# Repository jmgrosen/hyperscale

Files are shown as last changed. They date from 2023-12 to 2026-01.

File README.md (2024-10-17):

# Hyperscale

A kitchen scale that helps you follow a recipe.

## Building

Export Gerbers from KiCAD for the PCB. Build STLs from OpenSCAD for the case.

An actual assembly guide is TODO!

For the firmware, install [the Xtensa rustc target](https://docs.esp-rs.org/book/installation/riscv-and-xtensa.html) and [espflash](https://docs.esp-rs.org/book/tooling/espflash.html) as described in the Rust on ESP Book. Then `cargo espflash flash`.

## Licensing

The physical design files are licensed under the CERN Open Hardware Licence Version 2 - Permissive.

The firmware code is licensed under MIT. However, due to its use of Slint, the resulting firmware as a whole is licensed under GPLv3.

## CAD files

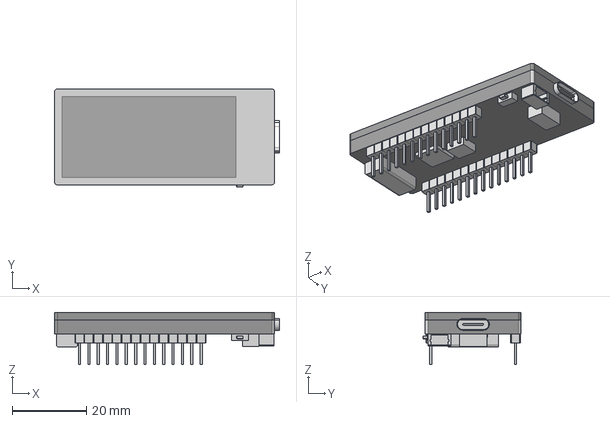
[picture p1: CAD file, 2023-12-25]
pcb/LILYGO T-Display-S3-AMOLED-Model.step
60.8 x 26.5 x 14.2 mm

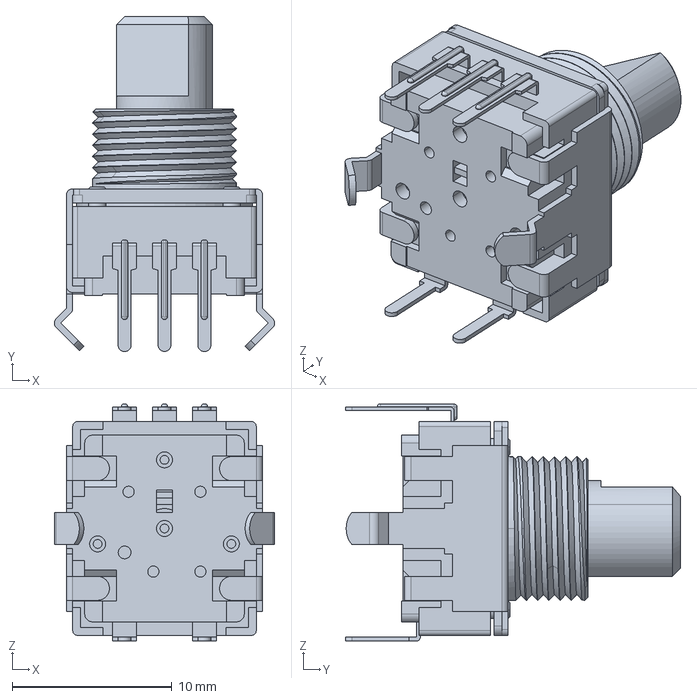
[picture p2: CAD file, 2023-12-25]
pcb/pec12r-3x17f-sxxxx.stp
13.8 x 21.0 x 14.8 mm

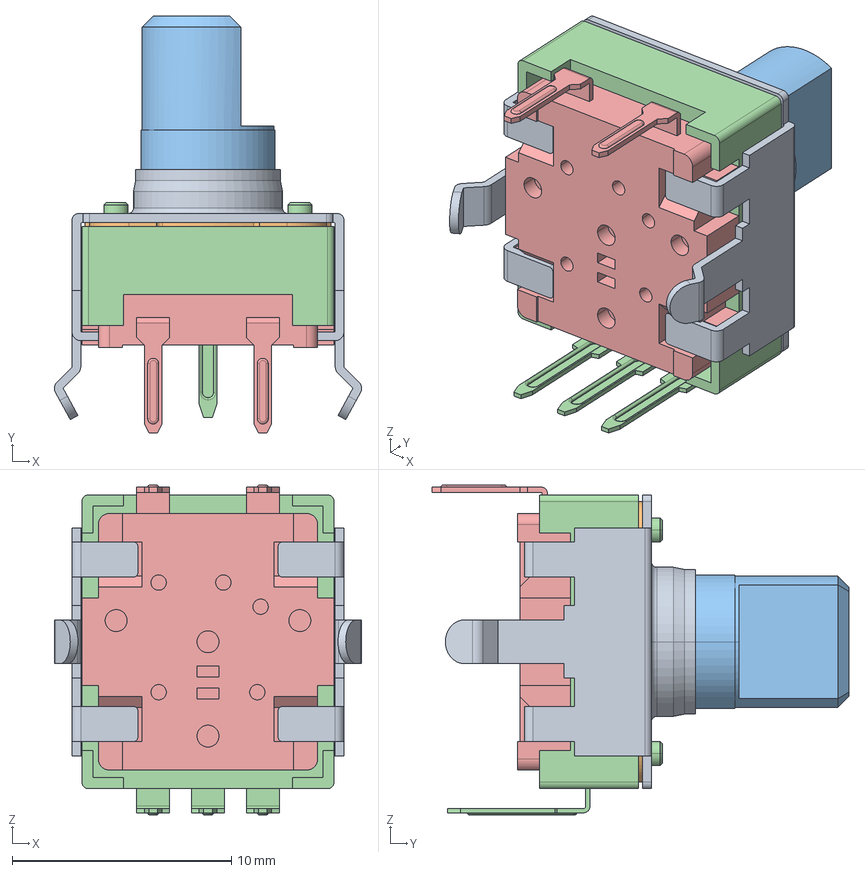
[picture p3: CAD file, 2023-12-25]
pcb/pec12r-4215f-s0024.stp
14.0 x 19.0 x 15.1 mm
12-24-B
12-32-Y
12-14-C

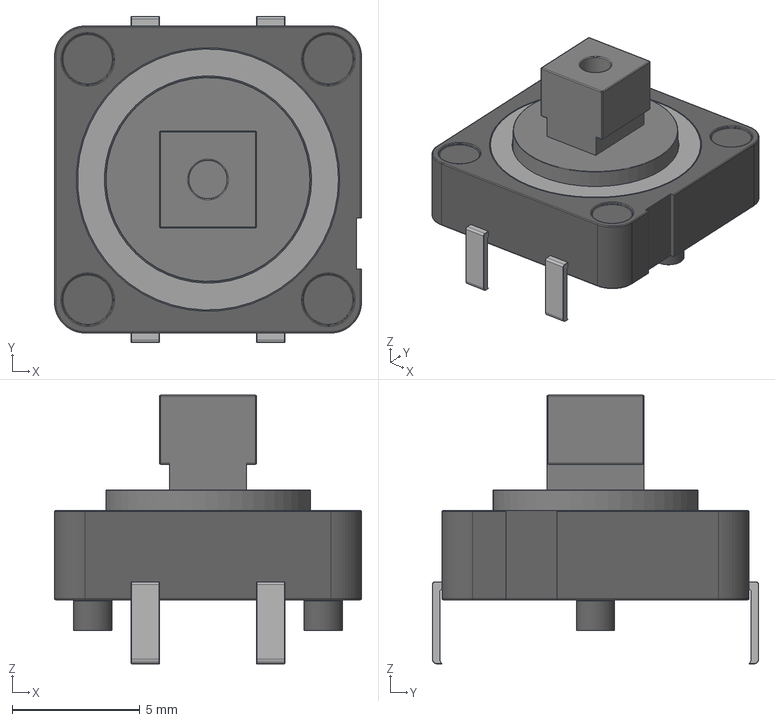
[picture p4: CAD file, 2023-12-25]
pcb/button round 12mm.step
12.0 x 12.8 x 10.5 mm

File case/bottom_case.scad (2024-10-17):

// Copyright (C) Jessie Grosen 2024
// SPDX-License-Identifier: CERN-OHL-P-2.0

include <BOSL2/std.scad>
include <BOSL2/rounding.scad>

include <common.scad>

/*
  ALL MEASUREMENTS IN MM
 */

/*
  TODO:
 */

PREVIEW = false;
PROTOTYPING = true;


strain_relief_maze = union([
  translate([0, 0], p=rect([STRAIN_RELIEF_WIDTH, BEND_RADIUS+2*STRAIN_RELIEF_WIDTH], anchor=TOP+LEFT)),
  translate([0, -BEND_RADIUS-STRAIN_RELIEF_WIDTH], p=rect([BEND_RADIUS+2*STRAIN_RELIEF_WIDTH, STRAIN_RELIEF_WIDTH], anchor=TOP+LEFT)),
  translate([BEND_RADIUS+STRAIN_RELIEF_WIDTH, 0], p=rect([BEND_RADIUS+2*STRAIN_RELIEF_WIDTH, STRAIN_RELIEF_WIDTH], anchor=TOP+LEFT)),
  translate([2*BEND_RADIUS+2*STRAIN_RELIEF_WIDTH, 0], p=rect([STRAIN_RELIEF_WIDTH, BEND_RADIUS*2+3*STRAIN_RELIEF_WIDTH], anchor=TOP+LEFT)),
  translate([BEND_RADIUS+STRAIN_RELIEF_WIDTH, -2*BEND_RADIUS-2*STRAIN_RELIEF_WIDTH], p=rect([BEND_RADIUS+2*STRAIN_RELIEF_WIDTH, STRAIN_RELIEF_WIDTH], anchor=TOP+LEFT)),
]);

rounding_start_depth = TOTAL_DEPTH - BACK_ROUNDING_RADIUS;
back_bottom_width = ROUNDING_START_WIDTH - 2*BACK_ROUNDING_RADIUS;
diagonal_width = (FRONT_BOTTOM_WIDTH - ROUNDING_START_WIDTH) / 2;
magnet_wall_offset = WIRE_TO_MAGNET_DIST + MAGNET_DIAMETER/2 + WALL_WIDTH;
base = move([-FRONT_BOTTOM_WIDTH/2, -TOTAL_DEPTH/2, 0], turtle([
  "turn", 90,
  "xymove", [diagonal_width, rounding_start_depth],
  "arcright", BACK_ROUNDING_RADIUS, 90,
  "move", back_bottom_width/2 - magnet_wall_offset,
  "turn", -90,
  "move", MAGNET_WALL_DEPTH_OFFSET,
  "turn", 90,
  "move", magnet_wall_offset * 2,
  "turn", 90,
  "move", MAGNET_WALL_DEPTH_OFFSET,
  "turn", -90,
  "move", back_bottom_width/2 - magnet_wall_offset,
  "arcright", BACK_ROUNDING_RADIUS, 90,
  "xymove", [diagonal_width, -rounding_start_depth],
]));

module below_pcb() {
  half_of(xrot(TILT_ANGLE, p=DOWN), cp=[0, 0, PCB_CENTER_HEIGHT], s=FRONT_BOTTOM_WIDTH*3)
    linear_extrude(height=TOP_CENTER_HEIGHT*2)
      polygon(base);
}

linear_extrude(height=BOTTOM_HEIGHT) polygon(base);

tilt_height = (TOTAL_DEPTH / 2) * tan(TILT_ANGLE);
total_height = TOP_CENTER_HEIGHT + tilt_height;

// perimeter wall
difference() {
  half_of(xrot(TILT_ANGLE, p=DOWN), cp=[0, 0, TOP_CENTER_HEIGHT], s=FRONT_BOTTOM_WIDTH*3)
    linear_extrude(height=TOP_CENTER_HEIGHT*2)
      offset_stroke(base, width=[0, -WALL_WIDTH], closed=true);
  translate([0, TOTAL_DEPTH / 2 - MAGNET_WALL_DEPTH_OFFSET, WIRE_HOLE_HEIGHT]) union() {
    teardrop(WALL_WIDTH*4, d=WIRE_HOLE_DIAMETER, $fn=20);
    if (PROTOTYPING) {
      cube([WIRE_HOLE_DIAMETER, WALL_WIDTH*4, TOP_CENTER_HEIGHT*2], anchor=BOTTOM);
    }
  }
  translate([0, 0, TOP_CENTER_HEIGHT-0.01]) xrot(TILT_ANGLE)
    translate(concat(PCB_OFFSET, [-BOTTOM_HEIGHT])) union() {
    for (cutout = FLANGE_CUTOUTS) {
      linear_extrude(height=BOTTOM_HEIGHT*3) polygon(cutout);
    }
  }
}

magnet_slot_rect = rect([MAGNET_DIAMETER, MAGNET_DEPTH]);

// magnet slots and strain relief
intersection() {
  below_pcb();
  union() {
    translate([0, TOTAL_DEPTH/2 - MAGNET_DEPTH/2 - MAGNET_WALL_DEPTH_OFFSET - WALL_WIDTH, 0]) xcopies(WIRE_TO_MAGNET_DIST * 2) {
      difference() {
        linear_extrude(height=MAGNET_HEIGHT) polygon(magnet_slot_rect);
        translate([0, -MAGNET_DEPTH/2 - 1, MAGNET_HEIGHT])
          #cylinder(h=MAGNET_DEPTH+2, d=MAGNET_DIAMETER, orient=BACK, $fn=40);
      }
      linear_extrude(height=MAGNET_HEIGHT + MAGNET_DIAMETER/2 + 1)
        offset_stroke(magnet_slot_rect, width=[0, WALL_WIDTH], closed=true);
    }
    color("blue") linear_extrude(total_height) translate([-BEND_RADIUS/2-STRAIN_RELIEF_WIDTH, 6, 0]) region(strain_relief_maze);
  }
}

intersection() {
  linear_extrude(height=total_height) polygon(base);
  // xrot(TILT_ANGLE) translate(concat(PCB_OFFSET, [PCB_CENTER_HEIGHT]))
  translate([0, 0, PCB_CENTER_HEIGHT])
    xrot(TILT_ANGLE)
      translate(PCB_OFFSET)
    color("red") union() {
    for (support = PCB_SUPPORTS) {
      zflip()
        linear_extrude(total_height)
          #region(support);
    }
    for (mount = MOUNT_POINTS) {
      translate(concat(mount, [0]))
        cylinder(MOUNT_POST_HEIGHT, r=MOUNT_POST_RADIUS, anchor=BOTTOM, $fn=20);
    }
  }
}

magnet_slot = translate([0, TOTAL_DEPTH/2], rect([magnet_wall_offset*2, MAGNET_WALL_DEPTH_OFFSET*4]));

translate([0, 0, TOP_CENTER_HEIGHT-0.01]) xrot(TILT_ANGLE)
// xrot(TILT_ANGLE) translate([0, 0, TOP_CENTER_HEIGHT-0.01])
union() {
  difference() {
    linear_extrude(height=BOTTOM_HEIGHT) union() {
      // offset_stroke(base, width=[0, -WALL_WIDTH]);
      region(difference(offset(top_flange, r=WALL_WIDTH, closed=true), base));
      offset_stroke(move([-FRONT_BOTTOM_WIDTH/2, -TOTAL_DEPTH/2, 0], turtle([
	"turn", 90,
	"xymove", [diagonal_width, rounding_start_depth],
	"arcright", BACK_ROUNDING_RADIUS, 90,
      ])), width=[0, -WALL_WIDTH], end="round");
      offset_stroke(move([FRONT_BOTTOM_WIDTH/2, -TOTAL_DEPTH/2, 0], turtle([
	"turn", 90,
	"xymove", [-diagonal_width, rounding_start_depth],
	"arcleft", BACK_ROUNDING_RADIUS, 90,
      ])), width=[0, WALL_WIDTH], end="round");
    }
    translate([0, 0, -1]) linear_extrude(height=FLANGE_HEIGHT+2) polygon(magnet_slot);
    translate(concat(PCB_OFFSET, [-BOTTOM_HEIGHT])) union() {
      for (cutout = FLANGE_CUTOUTS) {
	linear_extrude(height=BOTTOM_HEIGHT*3) polygon(cutout);
      }
    }
  }
  difference() {
    linear_extrude(height=FLANGE_HEIGHT) offset_stroke(top_flange, width=[0, -WALL_WIDTH], closed=true);
    translate([0, 0, -1]) linear_extrude(height=FLANGE_HEIGHT+2) polygon(magnet_slot);
  }
}


if (PREVIEW) {
  translate([0, 0, PCB_CENTER_HEIGHT])
  xrot(TILT_ANGLE)
    translate(PCB_OFFSET)
      import("../pcb/scale_pcb.stl");
}

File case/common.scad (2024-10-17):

// Copyright (C) Jessie Grosen 2024
// SPDX-License-Identifier: CERN-OHL-P-2.0

FRONT_BOTTOM_WIDTH = 117;
ROUNDING_START_WIDTH = 115;
BACK_ROUNDING_RADIUS = 15;
TOTAL_DEPTH=35.5;
BOTTOM_HEIGHT = 1.5;
WALL_WIDTH = 1;
TOP_CENTER_HEIGHT = 10;
PCB_CENTER_HEIGHT = 5;
TILT_ANGLE = 10;

PCB_OFFSET = [-144, 52.3];
MOUNT_POINTS = [
  [101.854, -45.974],
  // [145.796, -45.974],
  [145.796, -63.246],
  [184.324, -54.356],
];
MOUNT_POST_RADIUS = 1.4;
MOUNT_POST_HEIGHT = 3;

WIRE_HOLE_DIAMETER = 4;
WIRE_HOLE_HEIGHT = 5.5;
WIRE_TO_MAGNET_DIST = 11.25;
MAGNET_DEPTH = 3;
MAGNET_DIAMETER = 8;
MAGNET_HEIGHT = 5.75;
MAGNET_WALL_DEPTH_OFFSET = 2.5;

EXTRA_WIDTH_PER_SIDE = 9;
FLANGE_HEIGHT = 4;

// in PCB coordinates
FLANGE_CUTOUTS = [
  translate([209.42 - 9.5, -41.81 - 8.5], p=rect([6, 8.5], anchor=TOP+LEFT)), // battery connector: 5x8 at x=-9, y=-9
  translate([209.42 - 5.5, -41.81 - 17.8], p=rect([5.4, 7.3], anchor=TOP+LEFT)), // qwiic connector
  translate([209.42 - 12.5, -41.81 - 22.3], p=rect([6, 4], anchor=TOP+LEFT)), // reset button
];

BEND_RADIUS = 5;
STRAIN_RELIEF_WIDTH = 1;
PCB_SUPPORTS = [
  translate([97, -45], p=rect([23, 25])),
  translate([105, -65], p=rect([7, 25])),
  translate([148, -65], p=rect([15, 13])),
  translate([184, -57], p=rect([60, 14])),

  // translate([144, -50], p=circle(d=4, $fn=20)),
];

top_flange = round_corners(rect([FRONT_BOTTOM_WIDTH + EXTRA_WIDTH_PER_SIDE*2, TOTAL_DEPTH + WALL_WIDTH/2]), radius=2, $fn=20);

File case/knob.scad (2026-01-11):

// Copyright (C) Jessie Grosen 2024
// SPDX-License-Identifier: CERN-OHL-P-2.0

include <BOSL2/std.scad>
include <BOSL2/rounding.scad>

KNOB_RADIUS = 12.7;
KNOB_THICKNESS = 5;
SHAFT_INSET = 1;
SHAFT_OUTER_RADIUS = 4;
SHAFT_INNER_RADIUS = 3;
SHAFT_THICKNESS = 6;
NOTCH_THICKNESS = 5;
NOTCH_OFFSET = 1.5;

difference() {
  union() {
    cylinder(r=KNOB_RADIUS, h=KNOB_THICKNESS, $fn=160);
    translate([0, 0, KNOB_THICKNESS - SHAFT_INSET])
      cylinder(r=SHAFT_OUTER_RADIUS, h=SHAFT_THICKNESS, $fn=80);
  }
  translate([0, 0, KNOB_THICKNESS - SHAFT_INSET]) difference() {
    cylinder(r=SHAFT_INNER_RADIUS, h=SHAFT_THICKNESS+1, $fn=80);
    translate([NOTCH_OFFSET, 0, 0])
      cube(
        [3*SHAFT_OUTER_RADIUS, 3*SHAFT_OUTER_RADIUS, NOTCH_THICKNESS],
        anchor=LEFT+BOTTOM
      );
  }
}

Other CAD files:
case/top_case.scad

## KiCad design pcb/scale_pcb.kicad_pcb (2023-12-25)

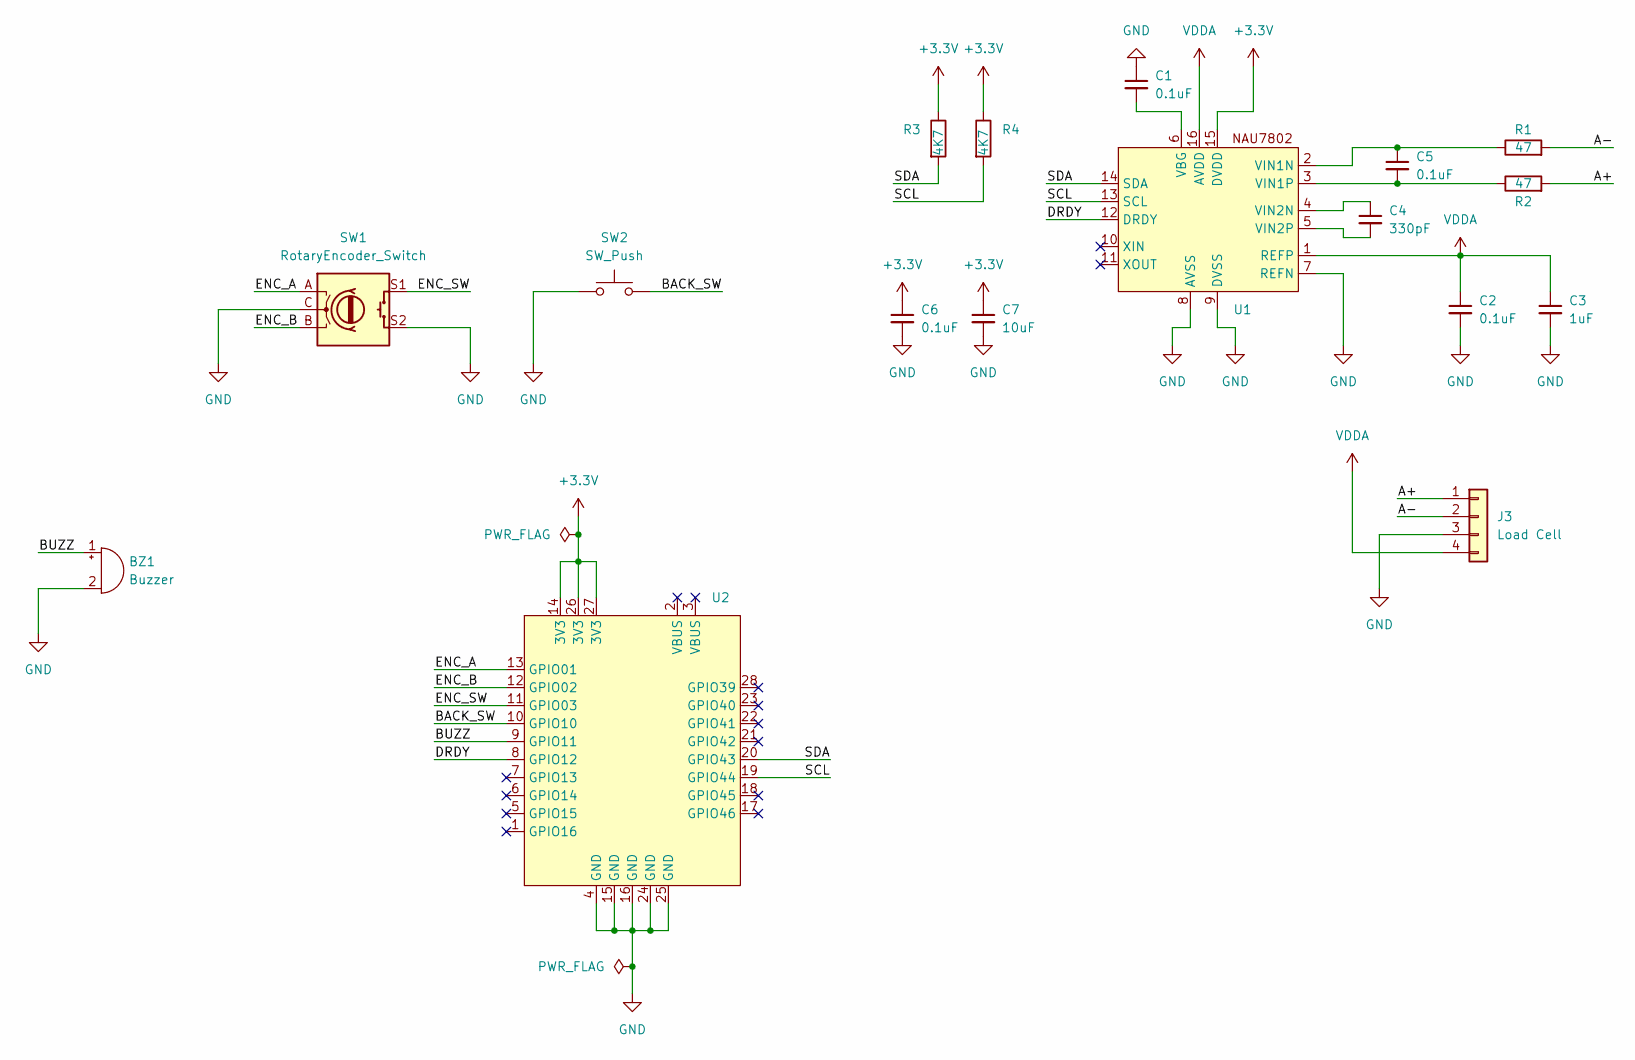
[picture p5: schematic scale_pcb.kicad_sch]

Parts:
BZ1: Buzzer; Buzzer_TDK_PS1240P02BT_D12.2mm_H6.5mm
C1, C2, C5, C6: 0.1uF; C_0805_2012Metric
C3: 1uF; C_0805_2012Metric
C4: 330pF; C_0805_2012Metric
C7: 10uF; C_1206_3216Metric
J3: Load Cell; PinHeader_1x04_P2.54mm_Vertical
R1, R2: 47; R_0805_2012Metric
R3, R4: 4K7; R_0805_2012Metric
SW1: RotaryEncoder_Switch; RotaryEncoder_Bourns_Vertical_PEC12R-3xxxF-Sxxxx
SW2: SW_Push; SW_PUSH-12mm
U1: SOP-16_3.9x9.9mm_P1.27mm
U2: LilyGo_T-Display-S3-AMOLED

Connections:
+3.3V: C6.1, C7.1, R3.1, R4.1, U1.15 (DVDD), U2.14 (3V3), U2.26 (3V3), U2.27 (3V3)
/A+: J3.1, R2.2
/A-: J3.2, R1.2
/BACK_SW: SW2.2, U2.10 (GPIO10)
/BUZZ: BZ1.1 (-), U2.9 (GPIO11)
/DRDY: U1.12 (DRDY), U2.8 (GPIO12)
/ENC_A: SW1.A, U2.13 (GPIO01)
/ENC_B: SW1.B, U2.12 (GPIO02)
/ENC_SW: SW1.S1, U2.11 (GPIO03)
/SCL: R4.2, U1.13 (SCL), U2.19 (GPIO44)
/SDA: R3.2, U1.14 (SDA), U2.20 (GPIO43)
GND: BZ1.2 (+), C1.1, C2.2, C3.2, C6.2, C7.2, J3.3, SW1.C, SW1.S2, SW2.1, U1.7 (REFN), U1.8 (AVSS), U1.9 (DVSS), U2.4 (GND), U2.15 (GND), U2.16 (GND), U2.24 (GND), U2.25 (GND)
unnamed: C1.2, U1.6 (VBG)
unnamed: C5.1, R1.1, U1.2 (VIN1N)
unnamed: C5.2, R2.1, U1.3 (VIN1P)
unnamed: C4.1, U1.4 (VIN2N)
unnamed: C4.2, U1.5 (VIN2P)
VDDA: C2.1, C3.1, J3.4, U1.1 (REFP), U1.16 (AVDD)

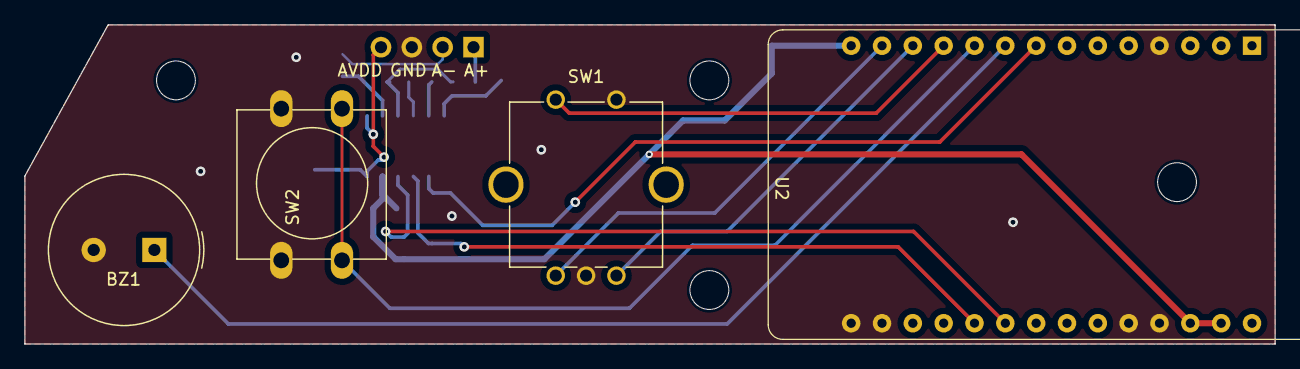
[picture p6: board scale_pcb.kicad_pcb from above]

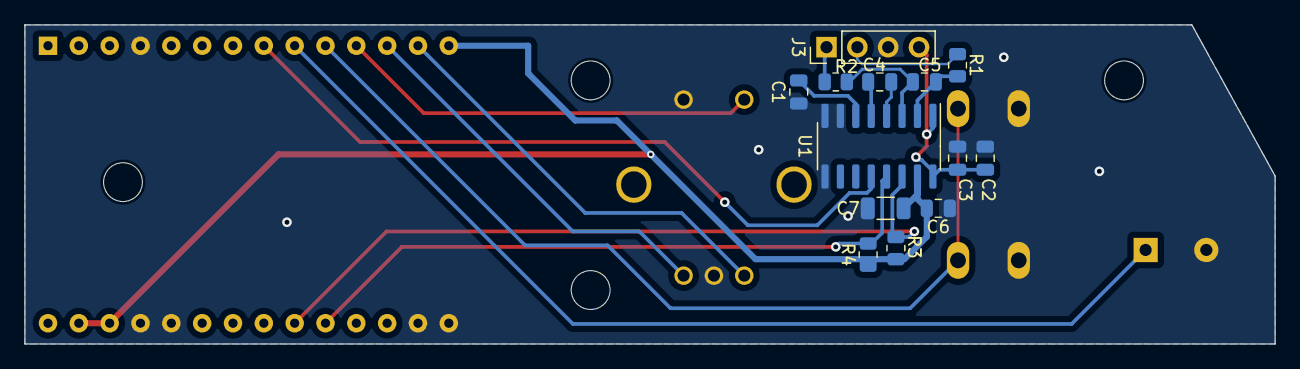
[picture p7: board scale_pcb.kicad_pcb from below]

Board: 2 copper layers, 103.0 x 26.3 mm, 17 parts (13 on the bottom side), 18 nets.

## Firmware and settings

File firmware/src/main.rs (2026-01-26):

// Copyright (C) Jessie Grosen 2024
// SPDX-License-Identifier: MIT

#![no_std]
#![no_main]

extern crate alloc;

use core::cell::RefCell;
use core::iter;
use core::mem;
use core::slice;

use alloc::boxed::Box;
use alloc::rc::Rc;
use alloc::vec::Vec;

use critical_section::Mutex;
use embedded_hal_1::delay::DelayNs;
use embedded_hal_1::digital::InputPin;
use embedded_hal_1::i2c::I2c as I2cTrait;
use esp_backtrace as _;
use esp_hal::sha::Sha;
use esp_println::println;
use esp_hal::{
    clock::CpuClock,
    timer::PeriodicTimer,
    timer::timg::TimerGroup, delay::Delay, rtc_cntl::Rtc,
    gpio::{Io, Input, InputConfig, Output, OutputConfig, Level, Pull, self},
    i2c::master::{I2c, Config as I2cConfig},
    spi::{Mode as SpiMode, master::{Spi, Config as SpiConfig}},
    time::{self, Rate},
    handler,
};
use esp_bootloader_esp_idf::partitions;
use esp_storage::FlashStorage;
use nau7802::AfeCalibrationStatus;
use rotary_encoder_hal::{Direction, Rotary, DefaultPhase};
use nau7802::Nau7802;
use heapless::spsc::{Queue, Producer};
use debouncr::{DebouncerStateful, Edge, Repeat6, debounce_stateful_6};

use slint::platform::software_renderer::RenderingRotation;
use slint::platform::software_renderer::{MinimalSoftwareWindow, Rgb565Pixel, TargetPixel, PremultipliedRgbaColor};
use slint::platform::{software_renderer as renderer, Platform, WindowEvent, Key};
use slint::{ComponentHandle, Model, ModelRc, PhysicalSize, VecModel};

use t_display_s3_amoled::rm67162::dma::RM67162Dma;
use t_display_s3_amoled::rm67162::Orientation;

esp_bootloader_esp_idf::esp_app_desc!();

#[derive(Debug, Clone, Copy)]
enum ButtonEvent {
    Press,
    Release,
    LongPress,
    LongRelease,
}

struct Button<P> {
    pin: P,
    debouncer: DebouncerStateful<u8, Repeat6>,
    held_for: u8,
}

const LONG_PRESS_TICKS: u8 = 100;

impl<P: InputPin> Button<P> {
    fn new(pin: P) -> Button<P> {
        Button { pin, debouncer: debounce_stateful_6(false), held_for: 0 }
    }

    fn update(&mut self) -> Option<ButtonEvent> {
        // logical low is logical high (pulled up)
        match self.debouncer.update(self.pin.is_low().unwrap()) {
            Some(Edge::Rising) => {
                self.held_for = 0;
                Some(ButtonEvent::Press)
            },
            Some(Edge::Falling) =>
                Some(if self.held_for > LONG_PRESS_TICKS {
                    ButtonEvent::LongRelease
                } else {
                    ButtonEvent::Release
                }),
            None if self.debouncer.is_high() => {
                self.held_for = self.held_for.saturating_add(1);
                if self.held_for > LONG_PRESS_TICKS {
                    Some(ButtonEvent::LongPress)
                } else {
                    None
                }
            },
            _ =>
                None,
        }
    }
}

#[derive(Debug, Clone, Copy)]
enum Event {
    WheelCW,
    WheelCCW,
    WheelButton(ButtonEvent),
    BackButton(ButtonEvent),
}

struct InterruptResources {
    encoder: Rotary<Input<'static>, Input<'static>, DefaultPhase>,
    producer: Producer<'static, Event, 16>,
    wheel_button: Button<Input<'static>>,
    back_button: Button<Input<'static>>,
    timer: PeriodicTimer<'static, esp_hal::Blocking>,
}

static INTERRUPT_RESOURCES: Mutex<RefCell<Option<InterruptResources>>> = Mutex::new(RefCell::new(None));

#[handler]
fn gpio_handler() {
    critical_section::with(|cs| {
        let mut borrowed_resources = INTERRUPT_RESOURCES.borrow_ref_mut(cs);
        let resources = borrowed_resources.as_mut().unwrap();
        match resources.encoder.update().unwrap() {
            Direction::Clockwise => { let _ = resources.producer.enqueue(Event::WheelCW); },
            Direction::CounterClockwise => { let _ = resources.producer.enqueue(Event::WheelCCW); },
            Direction::None => { },
        }
        let (pin_a, pin_b) = resources.encoder.pins();
        pin_a.clear_interrupt();
        pin_b.clear_interrupt();
    });
}

const TIMER_PERIOD_MS: u64 = 5;

#[handler]
fn timer0_handler() {
    critical_section::with(|cs| {
        let mut borrowed_resources = INTERRUPT_RESOURCES.borrow_ref_mut(cs);
        let resources = borrowed_resources.as_mut().unwrap();

        resources.timer.clear_interrupt();

        if let Some(event) = resources.wheel_button.update() {
            let _ = resources.producer.enqueue(Event::WheelButton(event));
        }
        if let Some(event) = resources.back_button.update() {
            let _ = resources.producer.enqueue(Event::BackButton(event));
        }
    });
}

const ONE_KG: f32 = 1.0 / 674500.0;

mod ui {
    slint::include_modules!();
}

struct Backend {
    window: Rc<renderer::MinimalSoftwareWindow>,
}

impl Platform for Backend {
    fn create_window_adapter(
        &self,
    ) -> Result<alloc::rc::Rc<dyn slint::platform::WindowAdapter>, slint::PlatformError> {
        // Since on MCUs, there can be only one window, just return a clone of self.window.
        // We'll also use the same window in the event loop.
        Ok(self.window.clone())
    }

    fn duration_since_start(&self) -> core::time::Duration {
        core::time::Duration::from_micros(
            time::Instant::now().duration_since_epoch().as_micros()
        )
    }

    // fn run_event_loop(&self) -> Result<(), slint::PlatformError>
    fn debug_log(&self, arguments: core::fmt::Arguments) {
        println!("Slint: {:?}", arguments);
    }
}

/*
struct DisplayWrapper<'a, CS> {
    display: &'a mut RM67162Dma<'a, CS>,
    line_buffer: &'a mut [Rgb565Pixel; 536],
}

impl<CS> renderer::LineBufferProvider for &mut DisplayWrapper<'_, CS>
where
    CS: embedded_hal_1::digital::OutputPin,
{
    type TargetPixel = Rgb565Pixel;

    fn process_line(
        &mut self,
        line: usize,
        range: core::ops::Range<usize>,
        render_fn: impl FnOnce(&mut [Self::TargetPixel]),
    ) {
        render_fn(&mut self.line_buffer[range.clone()]);

        let _ = self.display.fill_contiguous(
            &Rectangle::new(
                Point::new(range.start as _, line as _),
                Size::new(range.len() as _, 1),
            ),
            self.line_buffer[range.clone()]
                .iter()
                .map(|p| RawU16::new(p.0).into()),
        );
    }
}
*/

#[repr(transparent)]
#[derive(Copy, Clone, Debug, PartialEq, Eq, Default)]
struct Rgb565PixelFlipped(u16);

// lazy implementation
impl TargetPixel for Rgb565PixelFlipped {
    fn blend(&mut self, color: PremultipliedRgbaColor) {
        let mut pix = Rgb565Pixel((self.0 << 8) | (self.0 >> 8));
        pix.blend(color);
        self.0 = (pix.0 << 8) | (pix.0 >> 8);
    }

    fn from_rgb(r: u8, g: u8, b: u8) -> Rgb565PixelFlipped {
        let pix = Rgb565Pixel::from_rgb(r, g, b);
        Rgb565PixelFlipped((pix.0 << 8) | (pix.0 >> 8))
    }
}

fn cast_pixel_buffer(b: &[Rgb565PixelFlipped]) -> &[u8] {
    unsafe { slice::from_raw_parts(b.as_ptr() as *const u8, b.len() * 2) }
}

#[derive(Default)]
enum Scale<I: I2cTrait> {
    #[default]
    Empty,
    Unconnected(I),
    Calibrating(Nau7802<I>),
    Running { adc: Nau7802<I>, zero: i32, val: i32 },
}

impl<I: I2cTrait> Scale<I> {
    fn step_inner(self, wait: &mut impl DelayNs) -> (Self, Option<f32>) {
        use Scale::*;
        match self {
            Empty =>
                // this shouldn't happen :)
                (Empty, None),
            Unconnected(i2c) =>
                match Nau7802::new(i2c, wait) {
                    Ok(adc) =>
                        (Calibrating(adc), None),
                    Err((_, i2c)) =>
                        (Unconnected(i2c), None),
                },
            Calibrating(mut adc) =>
                if let Ok(AfeCalibrationStatus::Success) = adc.poll_afe_calibration_status() {
                    if let Ok(val) = adc.read() {
                        (Running { adc, zero: val, val }, Some(0.))
                    } else {
                        (Calibrating(adc), None)
                    }
                } else {
                    (Calibrating(adc), None)
                },
            Running { mut adc, zero, val } => {
                let new_val = adc.read().unwrap_or(val);
                (Running { adc, zero, val: new_val }, Some(((new_val - zero) as f32) * ONE_KG))
            },
        }
    }

    /// Steps the connecting/calibrating/running state
    /// machine. Returns the most recent reading if we have calibrated
    /// successfully.
    fn step(&mut self, wait: &mut impl DelayNs) -> Option<f32> {
        let real_self = mem::take(self);
        let (new_self, result) = real_self.step_inner(wait);
        let _ = mem::replace(self, new_self);
        result
    }

    fn rezero(&mut self) {
        if let &mut Scale::Running { ref mut zero, val, .. } = self {
            *zero = val;
        }
    }
}

fn progress_for_recipe(recipe: &ui::Recipe) -> ui::RecipeProgress {
    ui::RecipeProgress {
        scale_factor: 1.0,
        ingredient_progresses:
            iter::repeat(ui::IngredientProgress { done: false, amount: 0.0 })
            .take(recipe.ingredients.row_count())
            .collect::<Vec<_>>()[..]
            .into(),
    }
}

mod storage;

#[esp_hal::main]
fn main() -> ! {
    // init_heap();
    let config = esp_hal::Config::default().with_cpu_clock(CpuClock::max());
    let peripherals = esp_hal::init(config);

    esp_alloc::psram_allocator!(peripherals.PSRAM, esp_hal::psram);
    println!("initted psram");

    let mut sha = Sha::new(peripherals.SHA);

    let mut pt_mem = [0u8; partitions::PARTITION_TABLE_MAX_LEN];
    let _fs_region = storage::find_fs_region(&mut pt_mem, &mut FlashStorage::new(peripherals.FLASH), &mut sha);

    // Disable the RTC and TIMG watchdog timers
    let mut rtc = Rtc::new(peripherals.LPWR);
    let timer_group0 = TimerGroup::new(peripherals.TIMG0);
    let mut wdt0 = timer_group0.wdt;
    let timer_group1 = TimerGroup::new(peripherals.TIMG1);
    let mut wdt1 = timer_group1.wdt;
    rtc.rwdt.disable();
    wdt0.disable();
    wdt1.disable();
    println!("Hello board!");

    // Set GPIO4 as an output, and set its state high initially.
    let mut io = Io::new(peripherals.IO_MUX);
    io.set_interrupt_handler(gpio_handler);
    // let mut led = io.pins.gpio38.into_push_pull_output();
    // let _button = io.pins.gpio21.into_pull_down_input();

    // led.set_high().unwrap();

    // Initialize the Delay peripheral, and use it to toggle the LED state in a
    // loop.
    let mut delay = Delay::new();

    // set up rotary encoder
    let pullup = InputConfig::default().with_pull(Pull::Up);
    let mut pin_a = Input::new(peripherals.GPIO1, pullup);
    let mut pin_b = Input::new(peripherals.GPIO2, pullup);
    let event_queue: &'static mut Queue<Event, 16> = {
        static mut Q: Queue<Event, 16> = Queue::new();
        // we probably should not use &'static mut :)
        #[allow(static_mut_refs)]
        unsafe { &mut Q }
    };
    let (event_producer, mut event_consumer) = event_queue.split();

    let encoder_button = Input::new(peripherals.GPIO3, pullup);
    let back_button = Input::new(peripherals.GPIO10, pullup);

    let tearing_effect = Input::new(peripherals.GPIO9, InputConfig::default());

    let timer00 = timer_group0.timer0;
    critical_section::with(|cs| {
        pin_a.listen(gpio::Event::AnyEdge);
        pin_b.listen(gpio::Event::AnyEdge);
        let rotary = Rotary::new(pin_a, pin_b);
        let mut periodic_timer = PeriodicTimer::new(timer00);
        periodic_timer.set_interrupt_handler(timer0_handler);
        periodic_timer.listen();
        periodic_timer.start(time::Duration::from_millis(TIMER_PERIOD_MS)).unwrap();
        INTERRUPT_RESOURCES.borrow_ref_mut(cs).replace(InterruptResources {
            encoder: rotary,
            producer: event_producer,
            wheel_button: Button::new(encoder_button),
            back_button: Button::new(back_button),
            timer: periodic_timer,
        });
    });

    let i2c_config = I2cConfig::default().with_frequency(Rate::from_khz(100));
    let i2c = I2c::new(peripherals.I2C0, i2c_config).unwrap()
        .with_sda(peripherals.GPIO43)
        .with_scl(peripherals.GPIO44);
    let scale = Rc::new(RefCell::new(Scale::Unconnected(i2c)));

    println!("init display");

    let sclk = peripherals.GPIO47;
    let rst = peripherals.GPIO17;
    let cs = peripherals.GPIO6;

    let d0 = peripherals.GPIO18;
    let d1 = peripherals.GPIO7;
    let d2 = peripherals.GPIO48;
    let d3 = peripherals.GPIO5;

    let cs = Output::new(cs, Level::High, OutputConfig::default());

    let mut rst = Output::new(rst, Level::Low, OutputConfig::default());

    let spi = Spi::new(
        peripherals.SPI2, // use spi2 host
        SpiConfig::default()
            .with_frequency(Rate::from_mhz(75)) // max 75MHz
            .with_mode(SpiMode::_0),
        )
        .unwrap()
        .with_sck(sclk)
        .with_sio0(d0)
        .with_sio1(d1)
        .with_sio2(d2)
        .with_sio3(d3)
        .with_dma(peripherals.DMA_CH0);

    let mut display = RM67162Dma::new(spi, cs);
    display.reset(&mut rst, &mut delay).unwrap();
    display.init(&mut delay).unwrap();
    display
        .set_orientation(Orientation::Portrait)
        .unwrap();

    println!("display init ok");

    let window = MinimalSoftwareWindow::new(renderer::RepaintBufferType::ReusedBuffer);
    slint::platform::set_platform(Box::new(Backend {
        window: window.clone(),
    }))
    .unwrap();
    // window.dispatch_event(WindowEvent::ScaleFactorChanged { scale_factor: 2.0 });
    window.set_size(PhysicalSize::new(536, 240));

    let ui = ui::AppWindow::new().unwrap();
    let _ui_handle = ui.as_weak();

    let mut framebuf = [Rgb565PixelFlipped(0); 536*240];

    let scale_ref = scale.clone();
    ui.global::<ui::ScaleControls>().on_zero(move || {
        scale_ref.borrow_mut().rezero();
    });

    let recipes = storage::default_recipes().into_iter().map(|r| r.into()).collect::<Vec<_>>();
    let progresses = recipes.iter().map(progress_for_recipe).collect::<Vec<_>>()[..].into();
    ui.set_recipes(ModelRc::new(VecModel::from(recipes)));
    ui.set_recipe_progresses(progresses);

    let mut i = 0;
    loop {
        loop {
            match event_consumer.dequeue() {
                Some(Event::WheelCW) => {
                    window.dispatch_event(WindowEvent::KeyPressed { text: Key::UpArrow.into() });
                    window.dispatch_event(WindowEvent::KeyReleased { text: Key::UpArrow.into() });
                },
                Some(Event::WheelCCW) => {
                    window.dispatch_event(WindowEvent::KeyPressed { text: Key::DownArrow.into() });
                    window.dispatch_event(WindowEvent::KeyReleased { text: Key::DownArrow.into() });
                },
                Some(Event::WheelButton(ButtonEvent::Press)) =>
                    window.dispatch_event(WindowEvent::KeyPressed { text: Key::RightArrow.into() }),
                Some(Event::WheelButton(ButtonEvent::Release)) =>
                    window.dispatch_event(WindowEvent::KeyReleased { text: Key::RightArrow.into() }),
                Some(Event::WheelButton(ButtonEvent::LongPress)) =>
                    window.dispatch_event(WindowEvent::KeyPressed { text: "d".into() }),
                Some(Event::WheelButton(ButtonEvent::LongRelease)) =>
                    window.dispatch_event(WindowEvent::KeyReleased { text: "d".into() }),
                Some(Event::BackButton(ButtonEvent::Press)) =>
                    window.dispatch_event(WindowEvent::KeyPressed { text: Key::LeftArrow.into() }),
                Some(Event::BackButton(ButtonEvent::Release)) =>
                    window.dispatch_event(WindowEvent::KeyReleased { text: Key::LeftArrow.into() }),
                Some(Event::BackButton(ButtonEvent::LongPress)) =>
                    window.dispatch_event(WindowEvent::KeyPressed { text: "b".into() }),
                Some(Event::BackButton(ButtonEvent::LongRelease)) =>
                    window.dispatch_event(WindowEvent::KeyReleased { text: "b".into() }),
                None =>
                    break
            }
        }

        let cur_weight = if let Some(weight) = scale.borrow_mut().step(&mut delay) {
            ui::ScaleStatus { valid: true, weight }
        } else {
            ui::ScaleStatus { valid: false, weight: 0. }
        };
        ui.set_current_weight(cur_weight);

        slint::platform::update_timers_and_animations();

        i += 1;
        if i > 230 {
            i = 0;
        }

        // Draw the scene if something needs to be drawn.
        window.draw_if_needed(|renderer| {
            renderer.set_rendering_rotation(RenderingRotation::Rotate90);
            // renderer.render_by_line(&mut wrapper);
            let before_render = now_us();
            renderer.render(&mut framebuf[..], 240);
            // renderer.render_by_line(&mut frame_buffer);
            let after_render = now_us();
            while tearing_effect.is_high() { }
            while tearing_effect.is_low() { }
            let after_wait = now_us();
            let _res = display.fill_with_framebuffer(cast_pixel_buffer(&framebuf[..]));
            let after_fill = now_us();
            println!(
                "render: {}us, wait: {}us, fill: {}us",
                after_render.wrapping_sub(before_render),
                after_wait.wrapping_sub(after_render),
                after_fill.wrapping_sub(after_wait),
            );
        });

        if !window.has_active_animations() {
            // if no animation is running, wait for the next input event
        }
    }
}

fn now_us() -> u64 {
    time::Instant::now().duration_since_epoch().as_micros()
}

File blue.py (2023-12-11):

from micropython import const

try:
    import asyncio
except ImportError:
    import uasyncio as asyncio
import aioble
import bluetooth

import struct


_WEIGHT_STRUCT = "<f"
_


def _encode_weight(w):
    return struct.pack(_WEIGHT_STRUCT, w)

_SCALE_SERVICE_UUID = bluetooth.UUID('8e639146-13cd-4c18-b6d2-1d0918cb611f')

_WEIGHT_CHARACTERISTIC_UUID = bluetooth.UUID('0335b3cd-f55b-49ed-b5f4-f641acab1b16')
_MAX_WEIGHT_CHARACTERISTIC_UUID = bluetooth.UUID('b602629f-f0a6-40a3-9eeb-30f0808712f7')
_ZERO_CHARACTERISTIC_UUID = bluetooth.UUID('33f2eaa8-d11e-493c-9f05-1f3cbf826f2c')
_ZEROED_CHARACTERISTIC_UUID = bluetooth.UUID('5cce657e-13bb-46dc-8fc1-1129463a3d93')

_SCALE_APPEARANCE = const(0x0c80)

# How frequently to send advertising beacons.
_ADV_INTERVAL_US = 250_000


# Register GATT server.
scale_service = aioble.Service(_SCALE_SERVICE_UUID)
weight_characteristic = aioble.Characteristic(
    scale_service, _WEIGHT_CHARACTERISTIC_UUID, read=True, notify=True
)
max_weight_characteristic = aioble.Characteristic(
    scale_service, _MAX_WEIGHT_CHARACTERISTIC_UUID, read=True, initial=_encode_weight(2.5)
)
zero_characteristic = aioble.Characteristic(
    scale_service, _ZERO_CHARACTERISTIC_UUID, write=True
)
zeroed_characteristic = aioble.Characteristic(
    scale_service, _ZEROED_CHARACTERISTIC_UUID, indicate=True
)
aioble.register_services(scale_service)


def update_weight(w):
    print(f"updating weight, {weight_characteristic._value_handle is not None}")
    weight_characteristic.write(_encode_weight(w), send_update=True)

# Serially wait for connections. Don't advertise while a central is
# connected.
async def peripheral_task():
    while True:
        async with await aioble.advertise(
            _ADV_INTERVAL_US,
            name="jessies-scale",
            services=[_SCALE_SERVICE_UUID],
            appearance=_SCALE_APPEARANCE,
        ) as connection:
            print("Connection from", connection.device)
            await connection.disconnected(timeout_ms=None)

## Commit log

2023-12-25 -> fw/
    [partitions.csv]
2023-12-25 add pcb
    [LILYGO T-Display-S3-AMOLED-Model.step, button round 12mm.step, pec12r-3x17f-sxxxx.stp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]
2024-01-06 case is looking good B-)
    [bottom_case.scad, common.scad, knob.scad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]
2024-10-17 add licenses and a minimal readme
    [bottom_case.scad, common.scad, knob.scad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]
2024-12-27 calibrate weight sensor in background after starting UI
2025-06-08 add missing ingredients to creme pat recipe
    [main.rs]
2026-01-11 tiny reformatting in case scad
    [knob.scad]
2026-01-26 writing recipes to fs seemingly working
    [partitions.csv]
